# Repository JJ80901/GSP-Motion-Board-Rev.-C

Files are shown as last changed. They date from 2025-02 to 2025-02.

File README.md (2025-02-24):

# GSP Wireless Motion Board Rev. C
**Wireless motion board for senior design at Missouri S&amp;T**

This board is designed to capture and wirelessly transmit motion data during a frisbee toss. It features an ESP32-C3-Mini-N4 microcontroller for efficient Bluetooth Low Energy (BLE) communication and an ICM-42670 high-precision 6DOF IMU for real-time motion tracking.

The primary goal of this project is to analyze key motion parameters of a frisbee throw, including initial spin rate (RPM), launch angle, stability, and acceleration. The ICM-42670 provides high-resolution accelerometer and gyroscope data, which allows for precise measurement of motion dynamics.

This design improves upon previous iterations by optimizing power efficiency and reducing form factor for future iterations. The onboard TLV62569DBVT switching regulator ensures stable power delivery to both the ESP32 and IMU. The compact size and BLE connectivity make this an ideal prototype for real-world frisbee motion analysis, with potential applications in sports analytics, biomechanics research, and performance optimization.

Schematic design by Josue Cavazos and Andrew Thomas

PCB Design led by Josue Cavazos

---

### What you'll find in this repository:
- Hardware designs (made in KiCad)
- Reference designs
- Device datasheets
- Circuit simulations

---

### Repository Project Structure:
- *3D Models* - Models for PCB components not found in the standard KiCad library
- *BOM* - An interactive HTML bill of materials (generated from the *Interactive HTML BOM* Plugin)
- *Datasheets* - Datasheets for specific devices used, such as the buck converter, transistors, battery charger, etc.
- *Docs* - Reference schematics used in the circuit design phase
- *Images* - High quality renderings of the final PCB in 3D
- *Libraries* - Folders to include schematic symbols and footprints for components not found in the standard KiCad library
- *Schematics* - PDFs of entire PCB schematic
- *Simulations* - LTSpice simulation block with any custom component libraries
- KiCad hardware design files

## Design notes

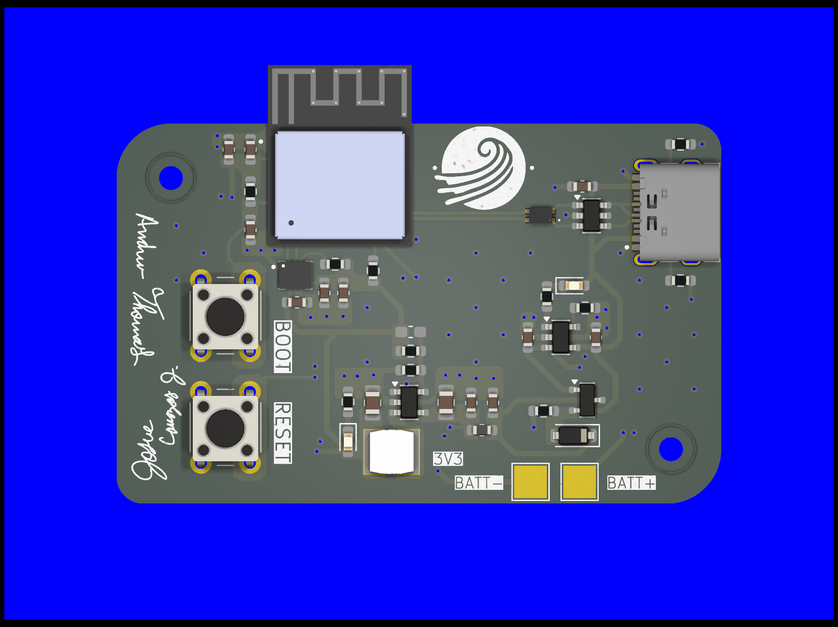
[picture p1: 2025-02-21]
Images/GSP RevC.png

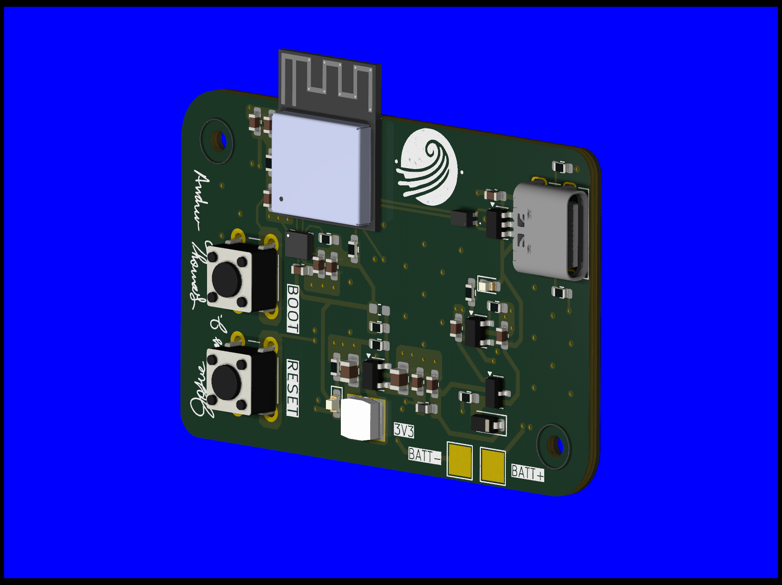
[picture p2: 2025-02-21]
Images/GSP RevC Iso.png

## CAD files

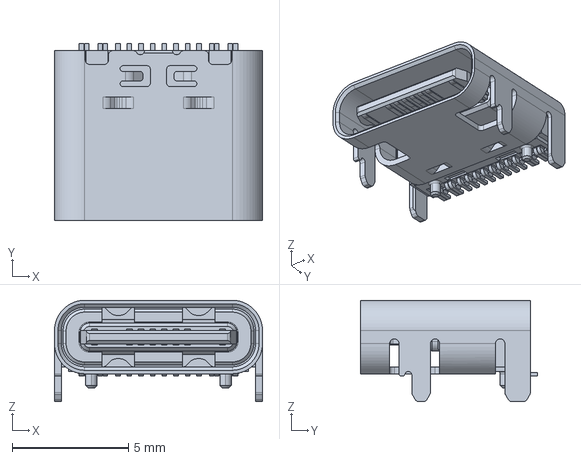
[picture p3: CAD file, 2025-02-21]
3D Models/USB-C.stp
8.94 x 7.60 x 4.36 mm

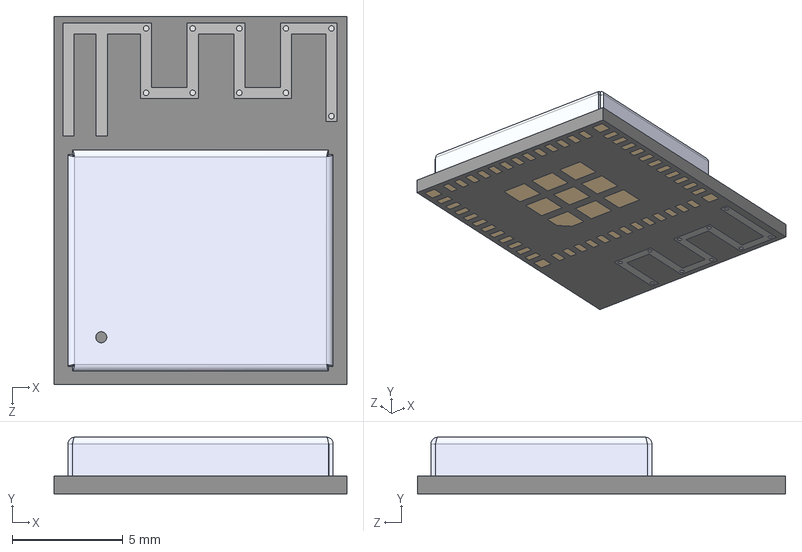
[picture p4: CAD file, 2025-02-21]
3D Models/ESP32-C3-MINI-1-N4.step
13.2 x 2.55 x 16.6 mm

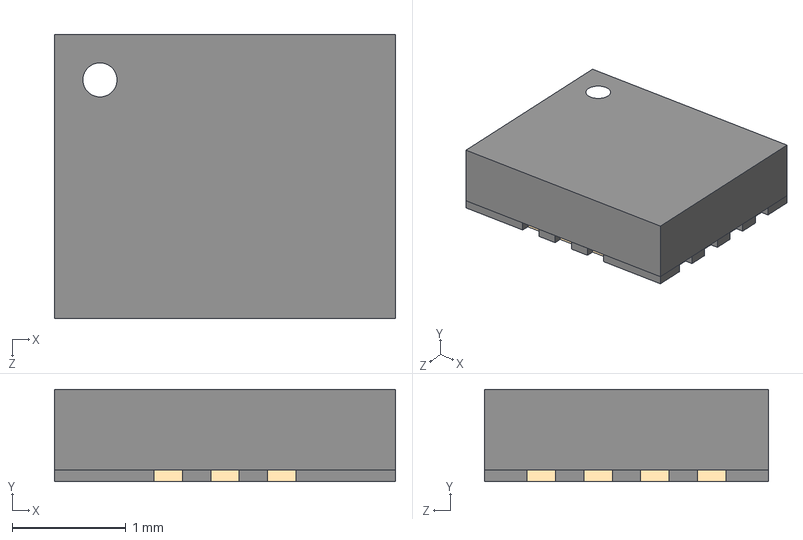
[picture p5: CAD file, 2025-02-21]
3D Models/ICM-42670-P.step
3.00 x 0.81 x 2.50 mm

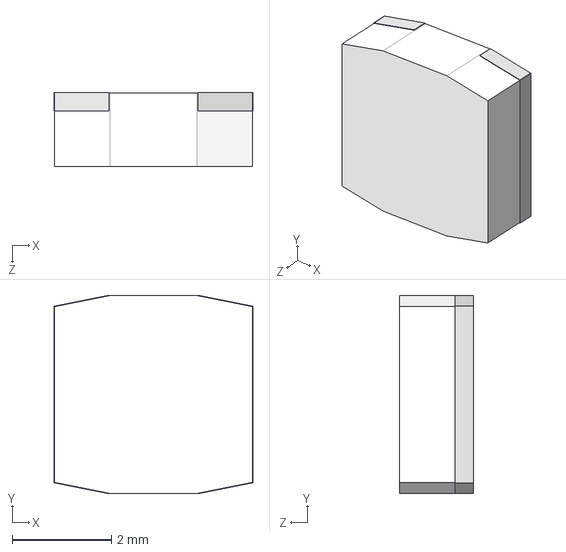
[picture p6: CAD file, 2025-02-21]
3D Models/PowerInductor.step
4.02 x 4.01 x 1.50 mm

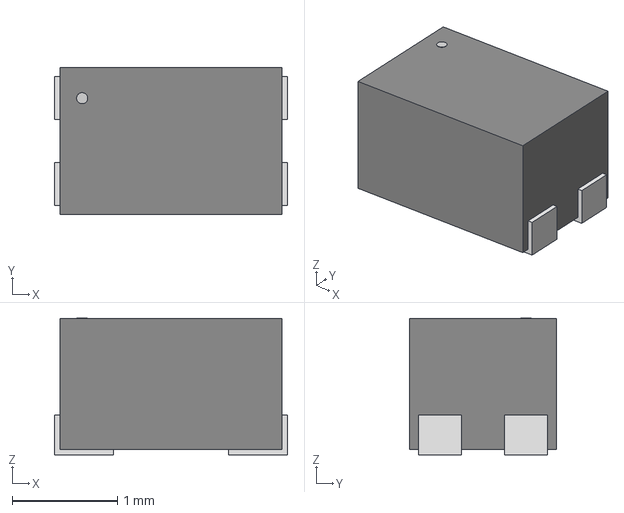
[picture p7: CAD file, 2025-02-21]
3D Models/CMC.step
2.21 x 1.40 x 1.30 mm

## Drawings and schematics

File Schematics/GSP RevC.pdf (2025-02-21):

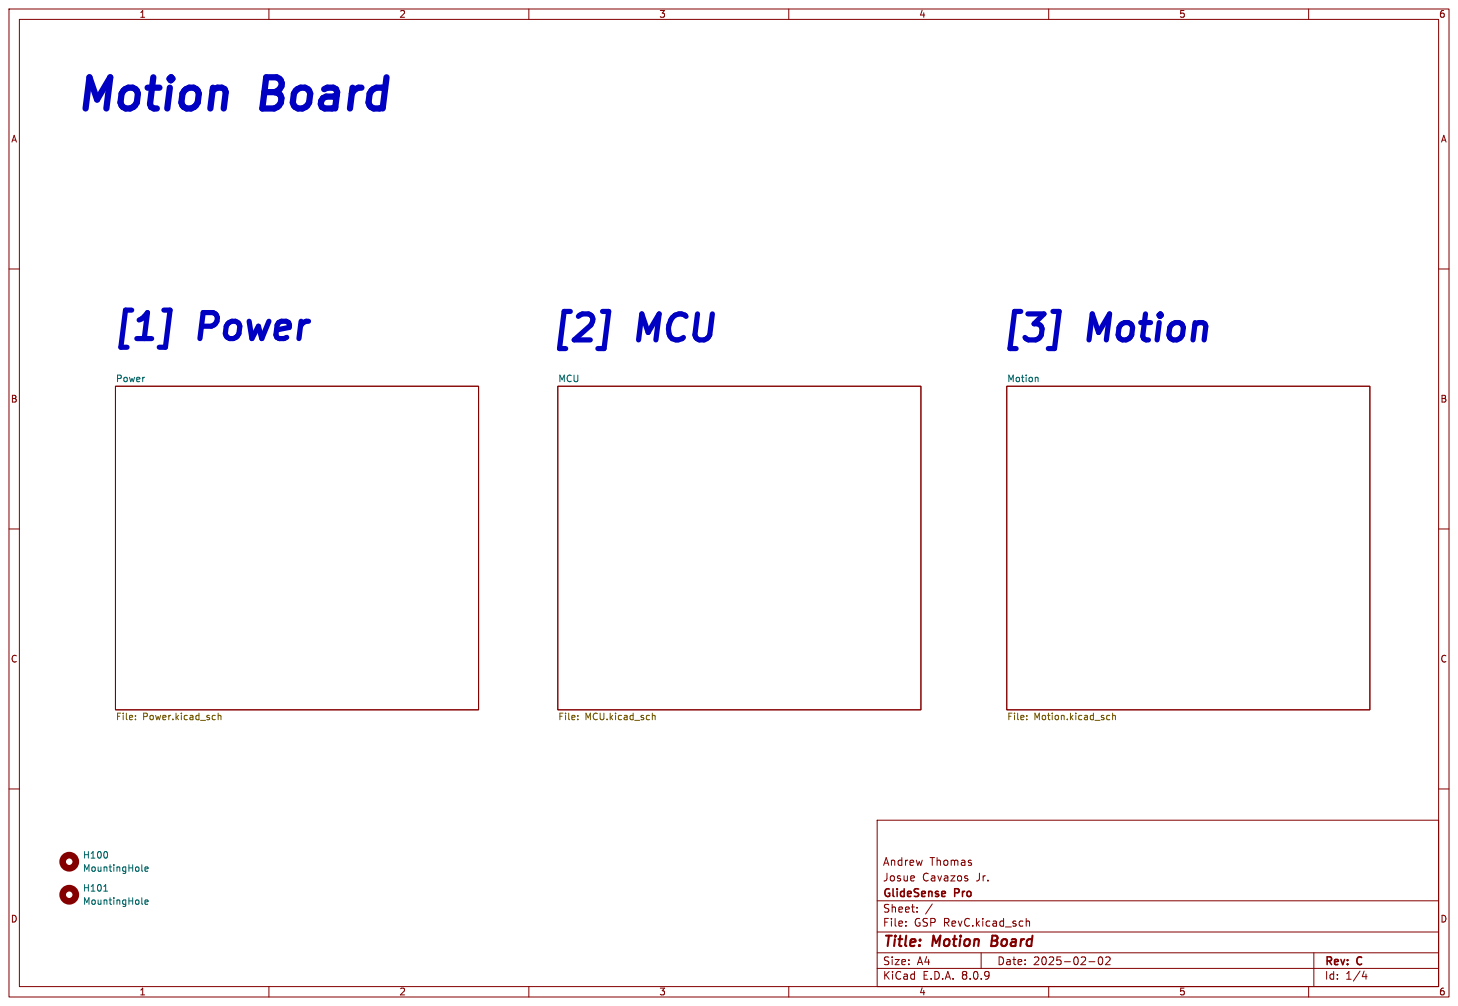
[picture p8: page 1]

File: MCU.kicad_sch H100 MountingHole H101 MountingHole

Josue Cavazos Jr. Andrew Thomas

Id: 1/4 Title: Motion Board

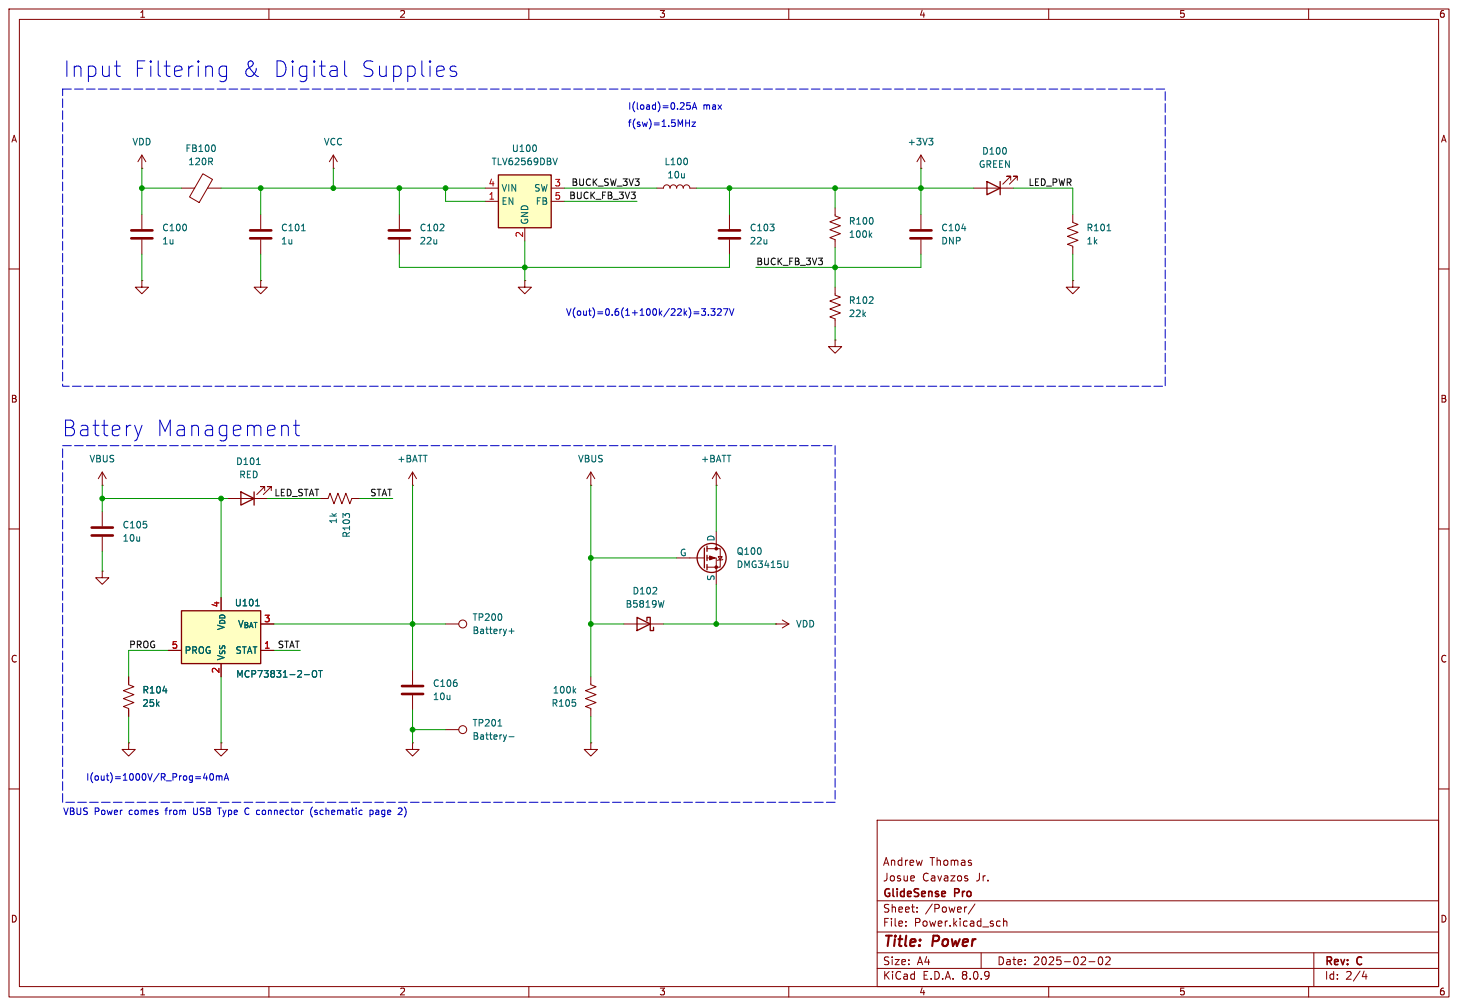
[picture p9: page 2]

Josue Cavazos Jr. Andrew Thomas

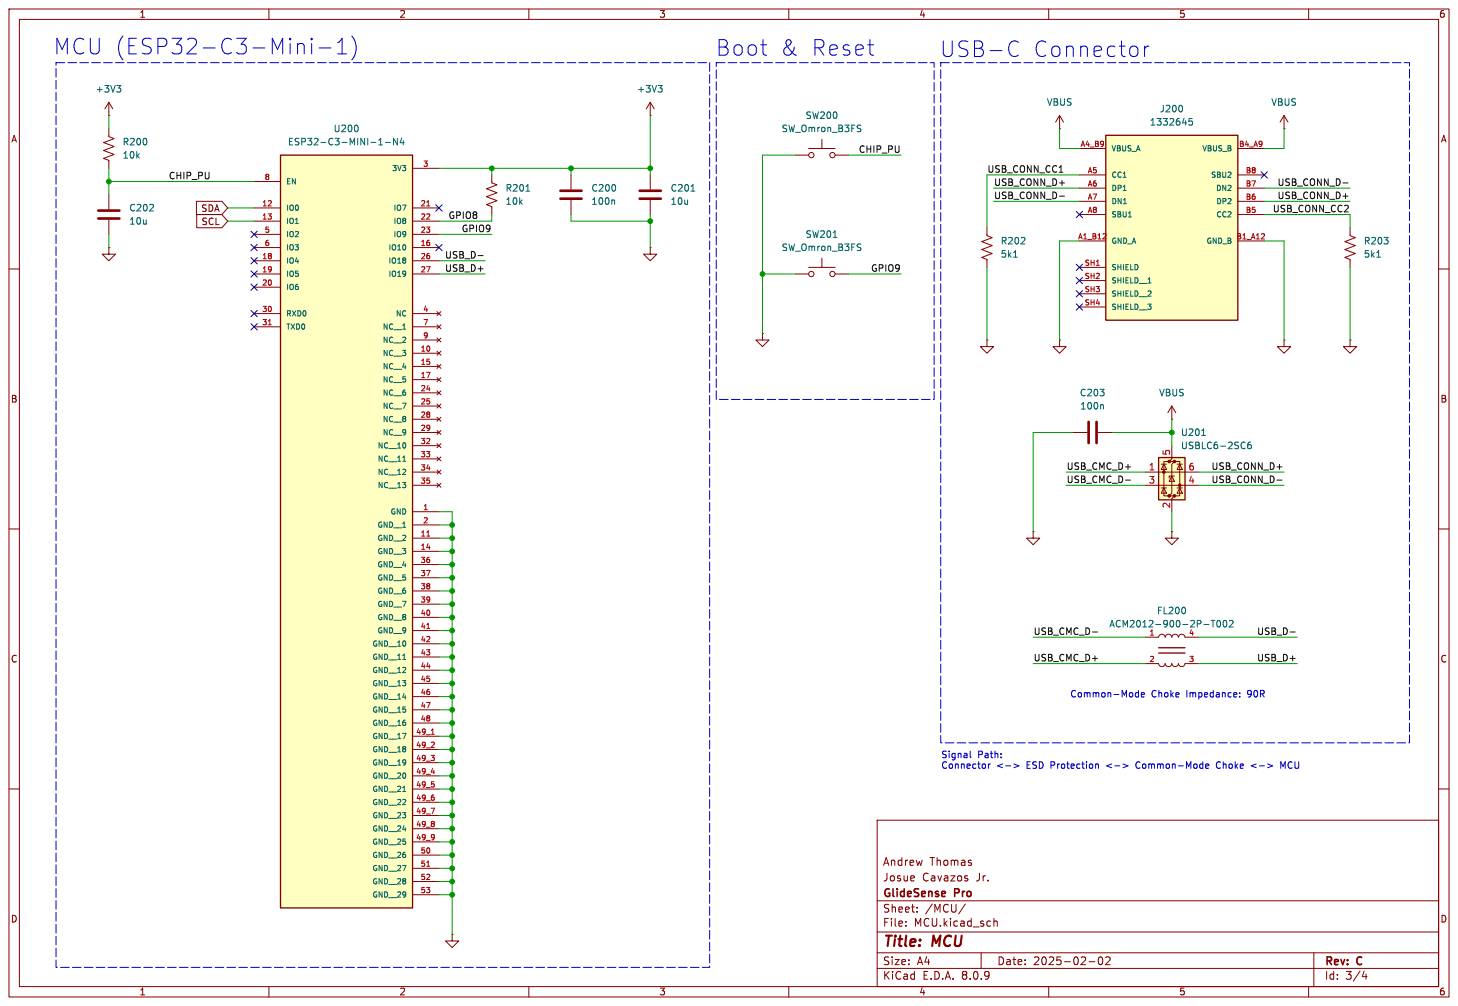
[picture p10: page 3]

Josue Cavazos Jr. Andrew Thomas

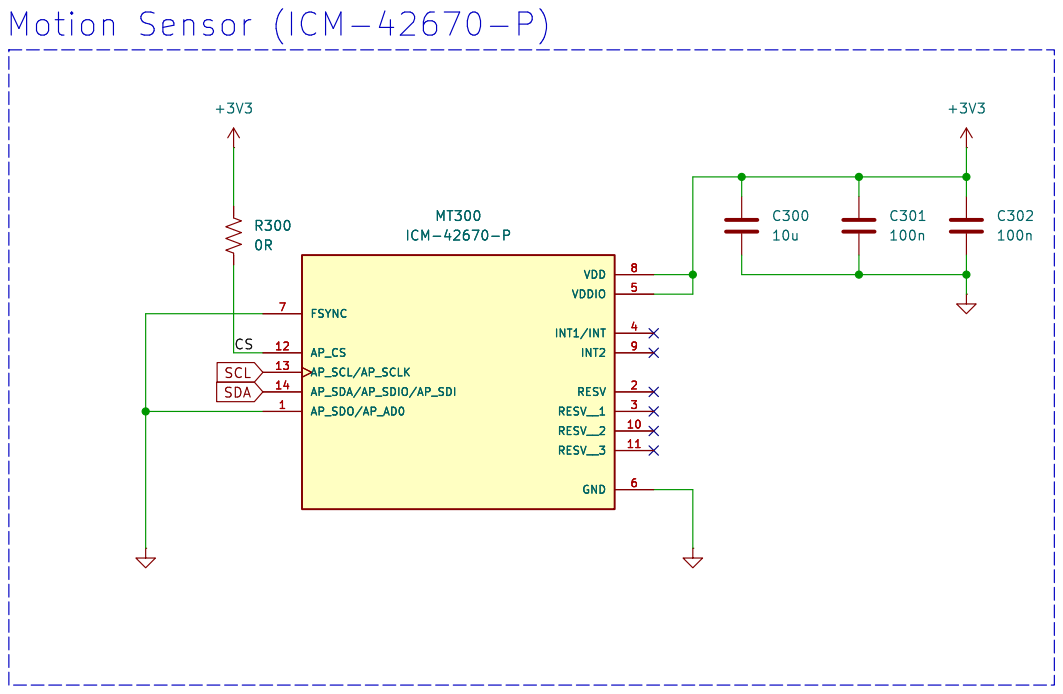
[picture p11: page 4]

Josue Cavazos Jr. Andrew Thomas

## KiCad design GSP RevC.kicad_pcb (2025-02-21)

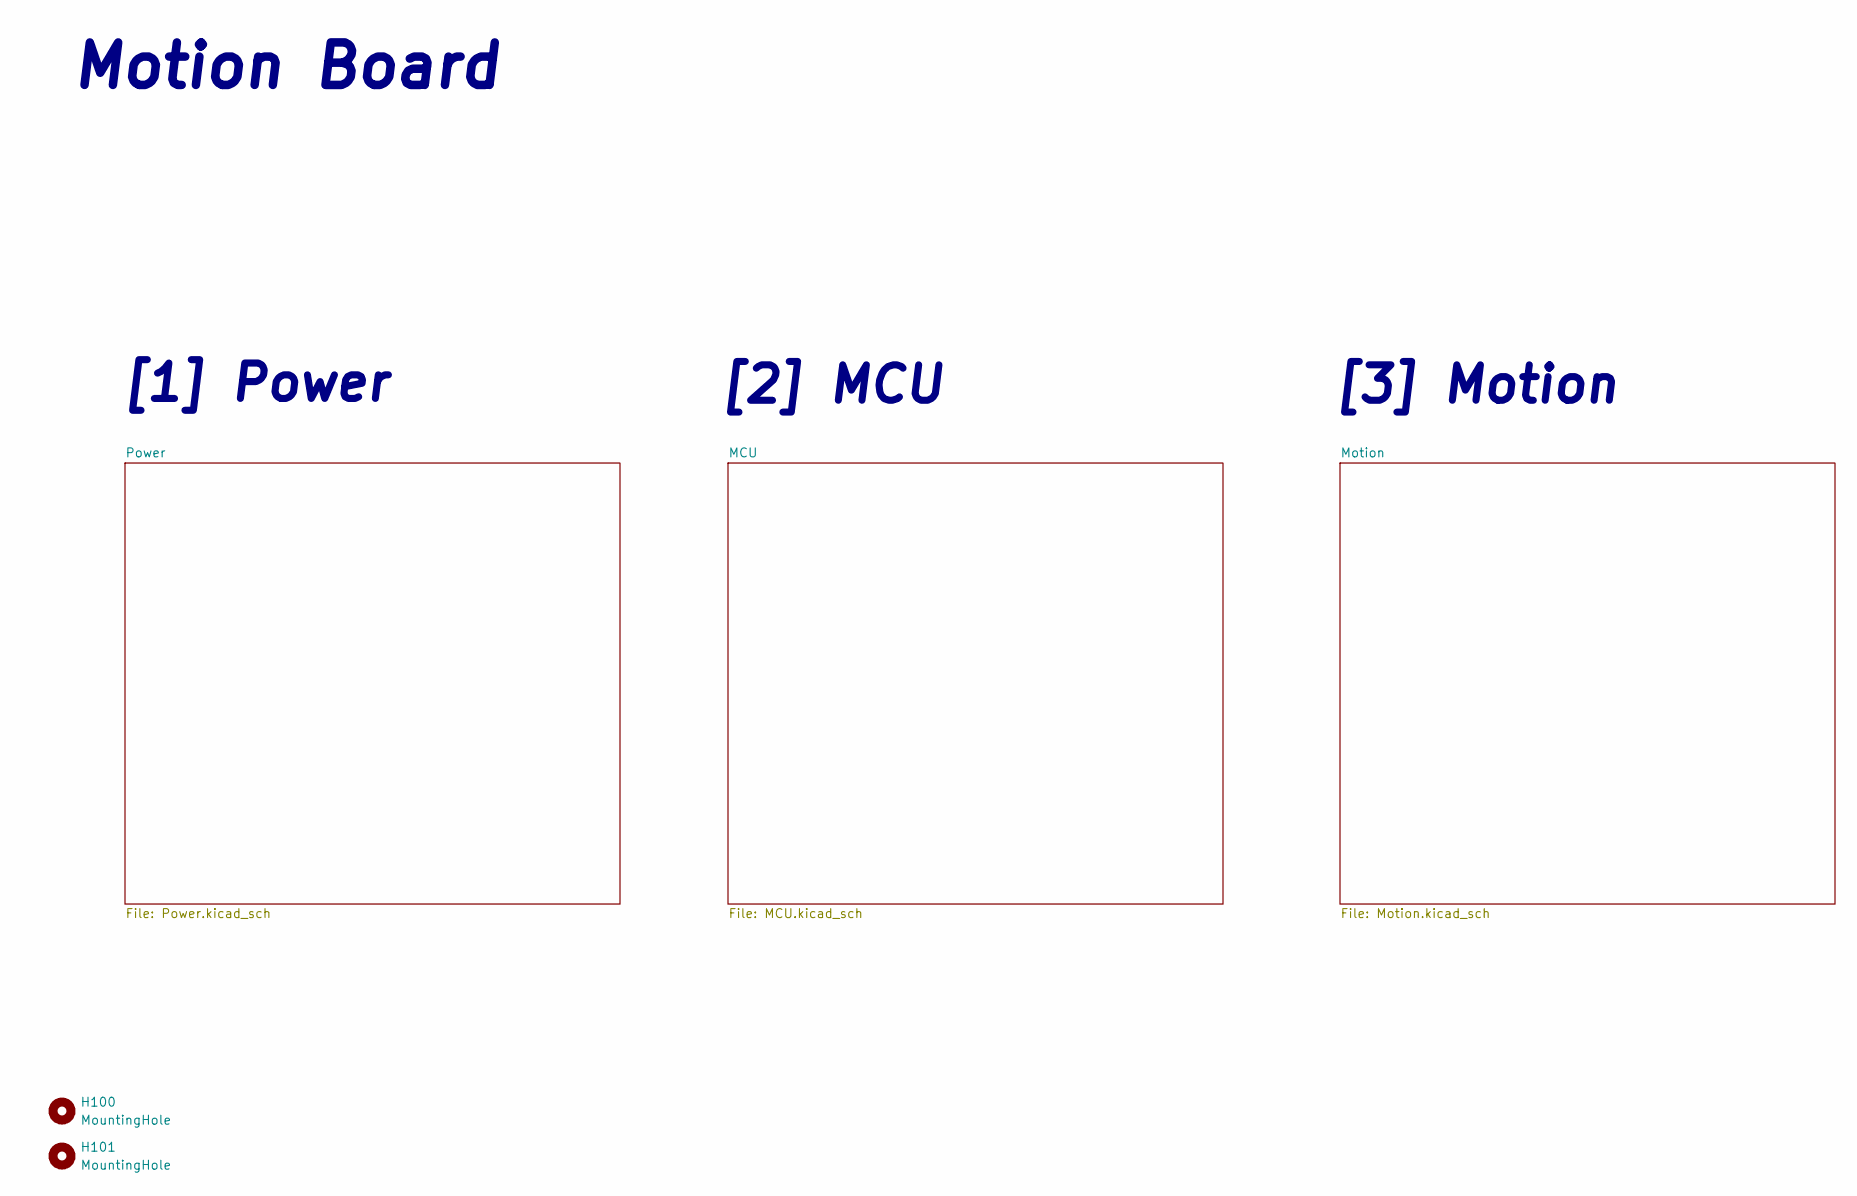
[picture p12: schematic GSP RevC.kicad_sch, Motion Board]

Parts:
H100, H101: MountingHole; MountingHole_2.2mm_M2

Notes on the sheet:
[2] MCU
[3] Motion
Motion Board
[1] Power

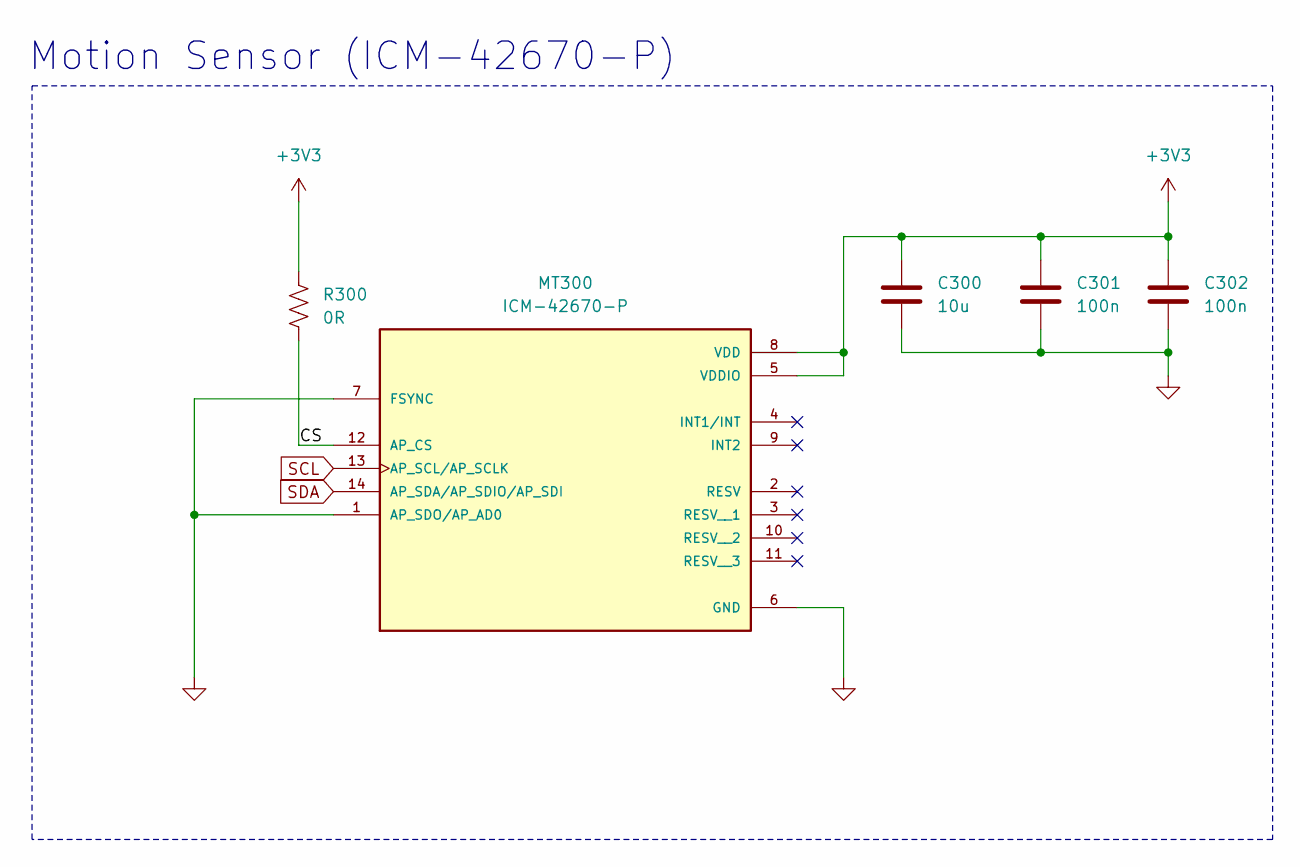
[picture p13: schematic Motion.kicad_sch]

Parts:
C300: 10u; C_0603_1608Metric_Pad1.08x0.95mm_HandSolder
C301, C302: 100n; C_0603_1608Metric_Pad1.08x0.95mm_HandSolder
MT300: ICM-42670-P; XDCR_ICM-42670-P; PARTREV 1.1
R300: 0R; R_0603_1608Metric_Pad0.98x0.95mm_HandSolder

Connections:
+3V3: C300.1, C301.1, C302.1, MT300.5 (VDDIO), MT300.8 (VDD), R300.1; also elsewhere on the board
/Motion/CS: MT300.12 (AP_CS), R300.2
GND: C300.2, C301.2, C302.2, MT300.1 (AP_SDO/AP_AD0), MT300.6 (GND), MT300.7 (FSYNC); also elsewhere on the board
SCL: MT300.13 (AP_SCL/AP_SCLK); also elsewhere on the board
SDA: MT300.14 (AP_SDA/AP_SDIO/AP_SDI); also elsewhere on the board

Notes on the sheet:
Motion Sensor (ICM-42670-P)

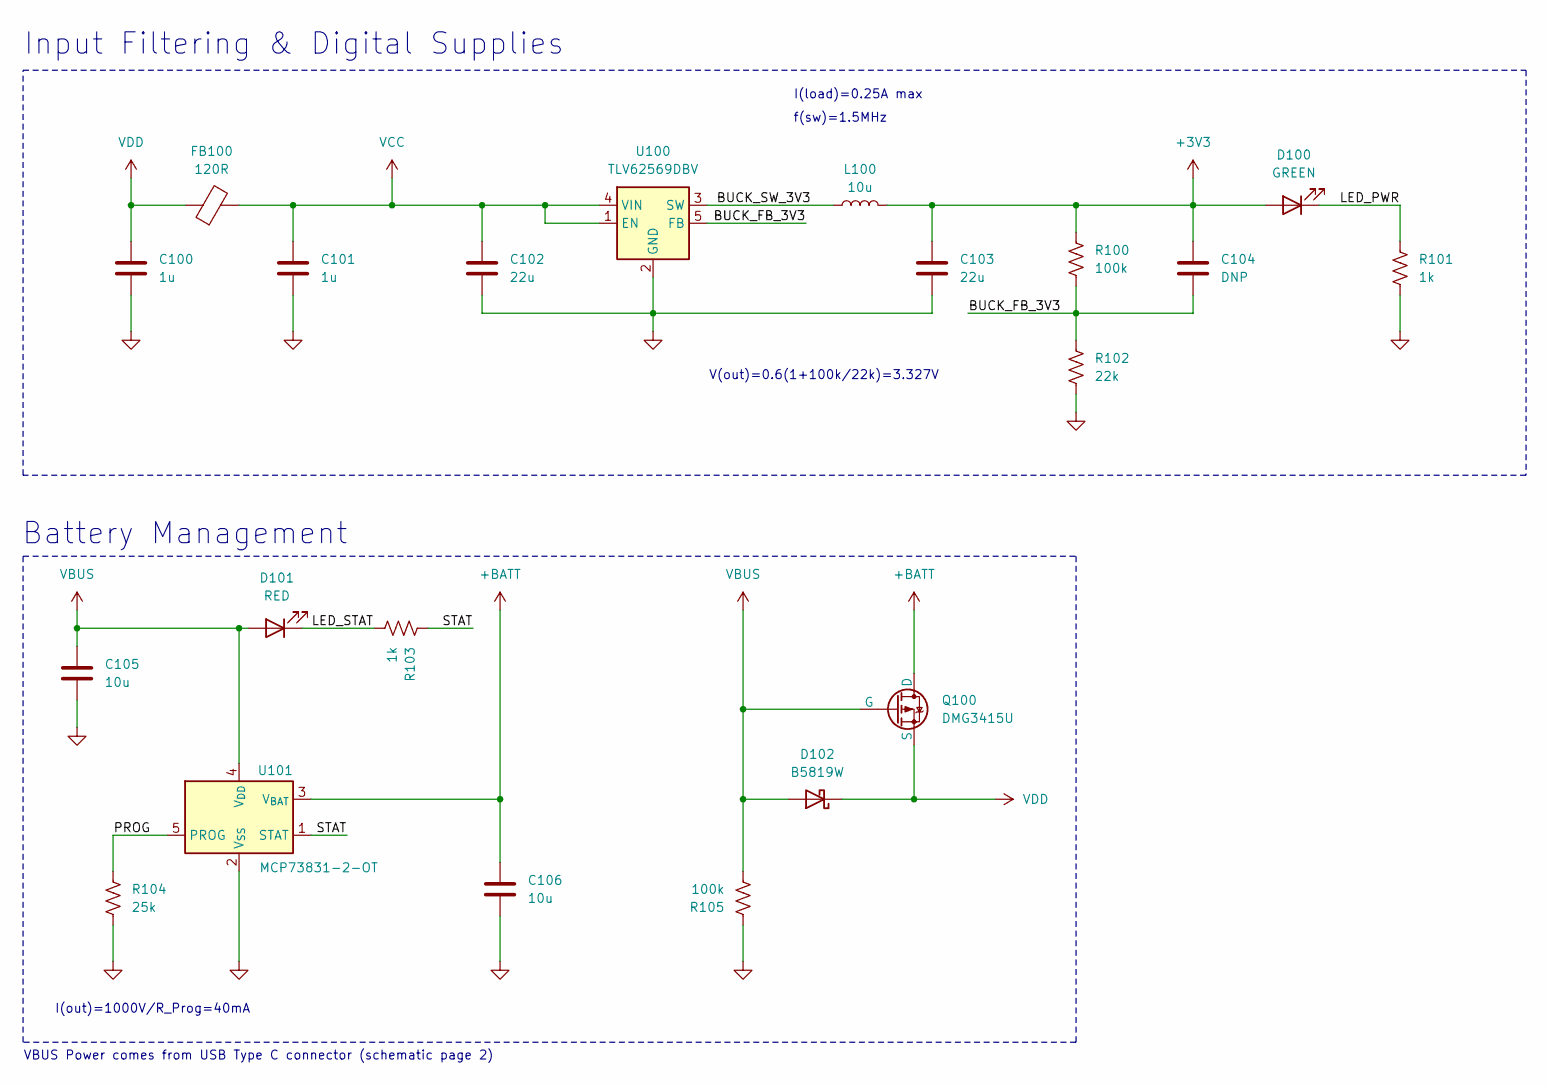
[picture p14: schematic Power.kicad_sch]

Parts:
C100, C101: 1u; C_0603_1608Metric_Pad1.08x0.95mm_HandSolder
C102, C103: 22u; C_0805_2012Metric_Pad1.18x1.45mm_HandSolder
C104: DNP; C_0603_1608Metric_Pad1.08x0.95mm_HandSolder
C105, C106: 10u; C_0603_1608Metric_Pad1.08x0.95mm_HandSolder
D100: GREEN; LED_0603_1608Metric_Pad1.05x0.95mm_HandSolder
D101: RED; LED_0603_1608Metric_Pad1.05x0.95mm_HandSolder
D102: B5819W; D_SOD-123
FB100: 120R; L_0603_1608Metric_Pad1.05x0.95mm_HandSolder
L100: 10u; IND_VLS4015CX-100M-H
Q100: DMG3415U; SOT-23
R100, R105: 100k; R_0603_1608Metric_Pad0.98x0.95mm_HandSolder
R101, R103: 1k; R_0603_1608Metric_Pad0.98x0.95mm_HandSolder
R102: 22k; R_0603_1608Metric_Pad0.98x0.95mm_HandSolder
R104: 25k; R_0603_1608Metric_Pad0.98x0.95mm_HandSolder
U100: TLV62569DBV; SOT-23-5
U101: MCP73831-2-OT; SOT-23-5

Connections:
+3V3: C103.1, C104.1, D100.2 (A), L100.2, R100.1; also elsewhere on the board
+BATT: C106.1, Q100.1 (D), U101.3 (V_{BAT}); also elsewhere on the board
/Power/BUCK_FB_3V3: C104.2, R100.2, R102.1, U100.5 (FB)
/Power/BUCK_SW_3V3: L100.1, U100.3 (SW)
/Power/LED_PWR: D100.1 (K), R101.1
/Power/LED_STAT: D101.1 (K), R103.2
/Power/PROG: R104.1, U101.5 (PROG)
/Power/STAT: R103.1, U101.1 (STAT)
GND: C100.2, C101.2, C102.2, C103.2, C105.2, C106.2, R101.2, R102.2, R104.2, R105.1, U100.2 (GND), U101.2 (V_{SS}); also elsewhere on the board
VBUS: C105.1, D101.2 (A), D102.2 (A), Q100.2 (G), R105.2, U101.4 (V_{DD}); also elsewhere on the board
VCC: C101.1, C102.1, FB100.2, U100.1 (EN), U100.4 (VIN)
VDD: C100.1, D102.1 (K), FB100.1, Q100.3 (S)

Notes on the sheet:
Battery Management
VBUS Power comes from USB Type C connector (schematic page 2)
V(out)=0.6(1+100k/22k)=3.327V
Input Filtering & Digital Supplies
I(load)=0.25A max
I(out)=1000V/R_Prog=40mA
f(sw)=1.5MHz

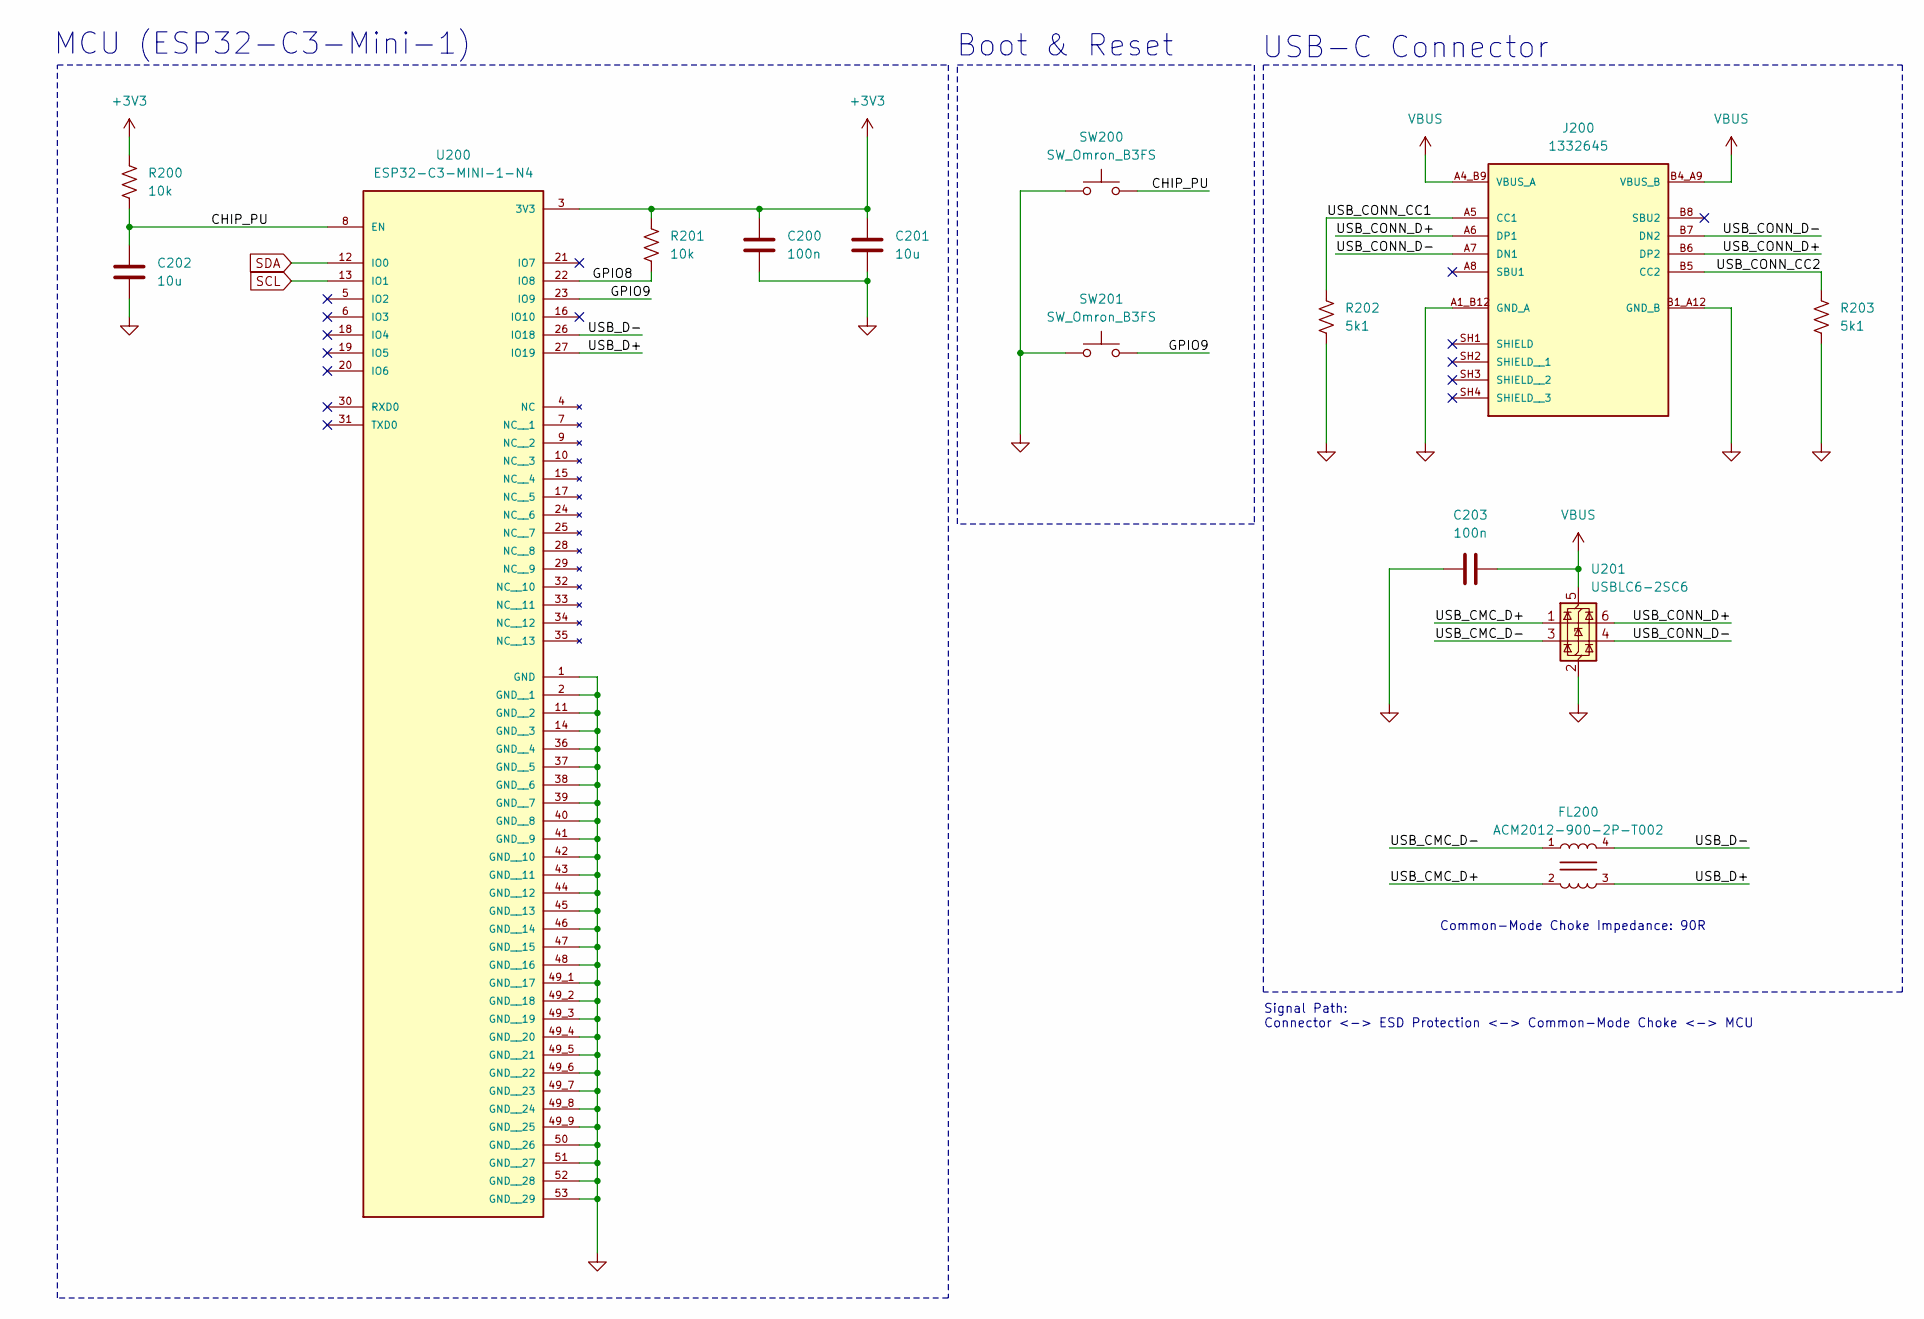
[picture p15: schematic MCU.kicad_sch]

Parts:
C200, C203: 100n; C_0603_1608Metric_Pad1.08x0.95mm_HandSolder
C201, C202: 10u; C_0603_1608Metric_Pad1.08x0.95mm_HandSolder
FL200: ACM2012-900-2P-T002; FIL_ACM2012-900-2P-T002
J200: 1332645; PHOENIX_1332645; PARTREV 17.01.2022
R200, R201: 10k; R_0603_1608Metric_Pad0.98x0.95mm_HandSolder
R202, R203: 5k1; R_0603_1608Metric_Pad0.98x0.95mm_HandSolder
SW200, SW201: SW_Omron_B3FS; SW_PUSH_6mm
U200: ESP32-C3-MINI-1-N4; XCVR_ESP32-C3-MINI-1-N4; PARTREV v1.0
U201: USBLC6-2SC6; SOT-23-6

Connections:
+3V3: C200.1, C201.1, R200.1, R201.1, U200.3 (3V3); also elsewhere on the board
/MCU/CHIP_PU: C202.1, R200.2, SW200.2, U200.8 (EN)
/MCU/GPIO8: R201.2, U200.22 (IO8)
/MCU/GPIO9: SW201.2, U200.23 (IO9)
/MCU/USB_CMC_D+: FL200.2, U201.1 (I/O1)
/MCU/USB_CMC_D-: FL200.1, U201.3 (I/O2)
/MCU/USB_CONN_CC1: J200.A5 (CC1), R202.1
/MCU/USB_CONN_CC2: J200.B5 (CC2), R203.1
/MCU/USB_CONN_D+: J200.A6 (DP1), J200.B6 (DP2), U201.6 (I/O1)
/MCU/USB_CONN_D-: J200.A7 (DN1), J200.B7 (DN2), U201.4 (I/O2)
/MCU/USB_D+: FL200.3, U200.27 (IO19)
/MCU/USB_D-: FL200.4, U200.26 (IO18)
GND: C200.2, C201.2, C202.2, C203.2, J200.A1_B12 (GND_A), J200.B1_A12 (GND_B), R202.2, R203.2, SW200.1, SW201.1, U200.1 (GND), U200.2 (GND__1), U200.11 (GND__2), U200.14 (GND__3), U200.36 (GND__4), U200.37 (GND__5), U200.38 (GND__6), U200.39 (GND__7), U200.40 (GND__8), U200.41 (GND__9), U200.42 (GND__10), U200.43 (GND__11), U200.44 (GND__12), U200.45 (GND__13), U200.46 (GND__14), U200.47 (GND__15), U200.48 (GND__16), U200.49_1 (GND__17), U200.49_2 (GND__18), U200.49_3 (GND__19), U200.49_4 (GND__20), U200.49_5 (GND__21), U200.49_6 (GND__22), U200.49_7 (GND__23), U200.49_8 (GND__24), U200.49_9 (GND__25), U200.50 (GND__26), U200.51 (GND__27), U200.52 (GND__28), U200.53 (GND__29), U201.2 (GND); also elsewhere on the board
SCL: U200.13 (IO1); also elsewhere on the board
SDA: U200.12 (IO0); also elsewhere on the board
VBUS: C203.1, J200.A4_B9 (VBUS_A), J200.B4_A9 (VBUS_B), U201.5 (VBUS); also elsewhere on the board

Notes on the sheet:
Signal Path: Connector <-> ESD Protection <-> Common-Mode Choke <-> MCU
USB-C Connector
Common-Mode Choke Impedance: 90R
Boot & Reset
MCU (ESP32-C3-Mini-1)

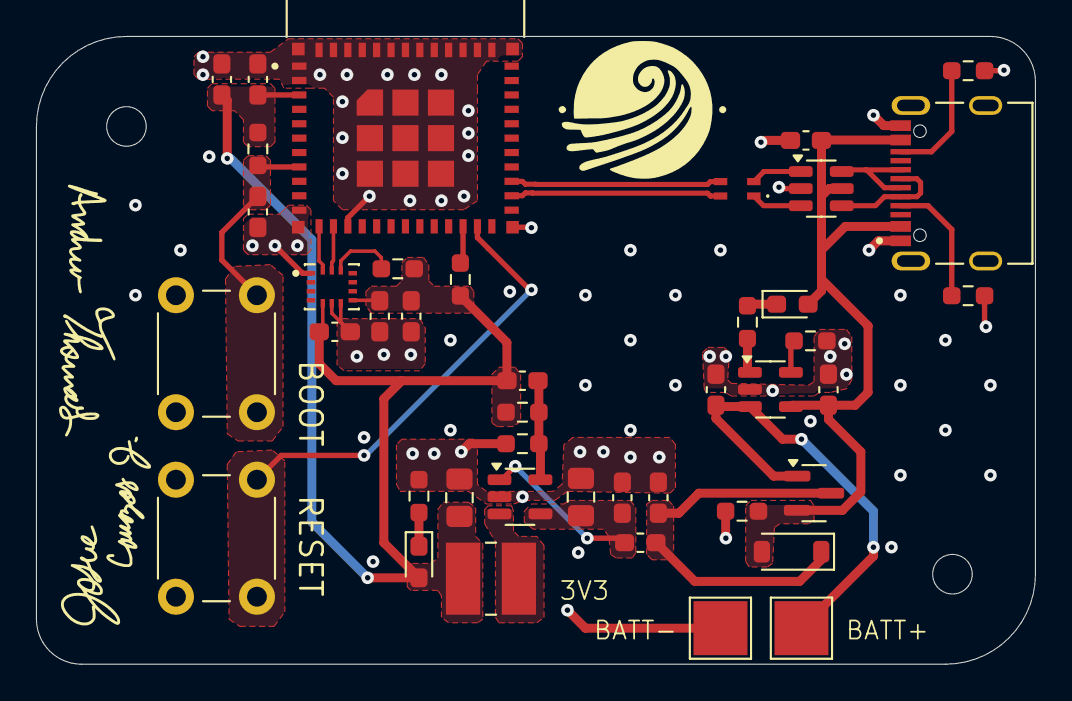
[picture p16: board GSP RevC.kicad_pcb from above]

Board: 4 copper layers, 55.5 x 34.9 mm, 44 parts (0 on the bottom side), 26 nets.

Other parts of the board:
TP200: Battery+; TestPoint_Pad_3.0x3.0mm
TP201: Battery-; TestPoint_Pad_3.0x3.0mm

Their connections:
+BATT: TP200.1; also elsewhere on the board
GND: TP201.1; also elsewhere on the board
